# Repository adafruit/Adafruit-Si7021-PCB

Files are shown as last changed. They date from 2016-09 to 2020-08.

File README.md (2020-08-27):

## Adafruit Si7021 Temperature & Humidity Sensor Breakout PCB
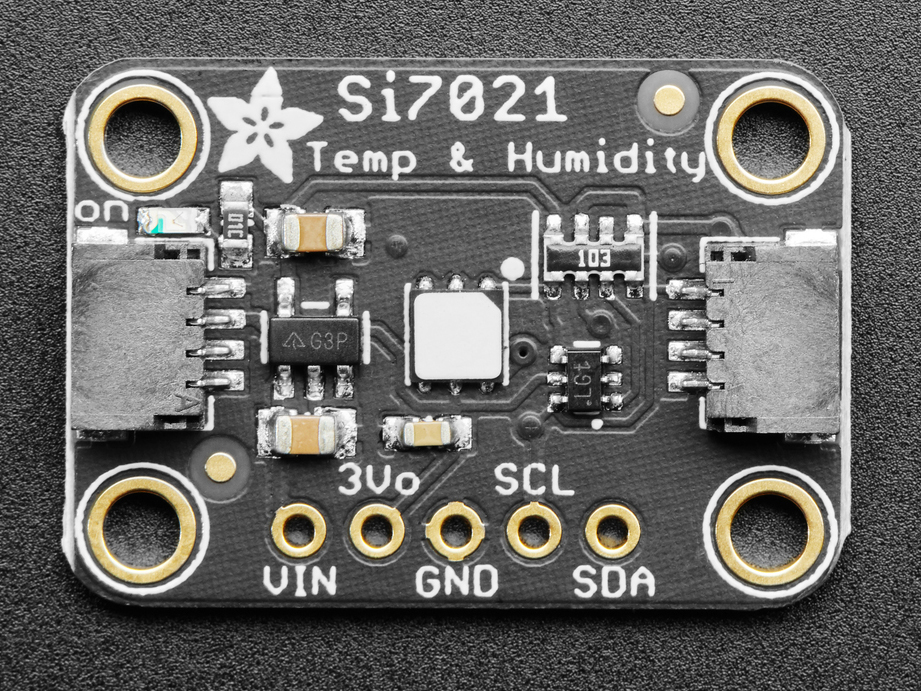
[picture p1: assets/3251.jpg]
<a href="http://www.adafruit.com/products/3251"><br/>
Click here to purchase one from the Adafruit shop</a>

It's summer and you're sweating and your hair's all frizzy and all you really want to know is why the weatherman said this morning that today's relative humidity would max out at a perfectly reasonable 42% when it feels more like 77%. Enter the Si7021 Temperature + Humidity Sensor - the best way to prove the weatherman wrong!

This lovely sensor for Silicon labs has ± 3% relative humidity measurements with a range of 0–80% RH, and ±0.4 °C temperature accuracy at a range of -10 to +85 °C. Great for all of your environmental sensing projects. It uses I2C for data transfer so it works with a wide range of microcontrollers.

To get you going fast, we spun up a custom made PCB in the STEMMA QT form factor, making them easy to interface with. The STEMMA QT connectors on either side are compatible with the SparkFun Qwiic I2C connectors. This allows you to make solderless connections between your development board and the LIS331s or to chain them with a wide range of other sensors and accessories using a compatible cable. We’ve of course broken out all the pins to standard headers and added a voltage regulator and level shifting so allow you to use it with either 3.3V or 5V systems such as the Raspberry Pi + Feather series or Arduino Uno respectively.

PCB files for the Adafruit Si7021 PCB. The format is EagleCAD schematic and board layout
- https://www.adafruit.com/products/3251

### License

Adafruit invests time and resources providing this open source design, please support Adafruit and open-source hardware by purchasing products from [Adafruit](https://www.adafruit.com)!

All text above must be included in any redistribution

Designed by Limor Fried/Ladyada for Adafruit Industries.
Creative Commons Attribution/Share-Alike, all text above must be included in any redistribution. 
See license.txt for additional information.

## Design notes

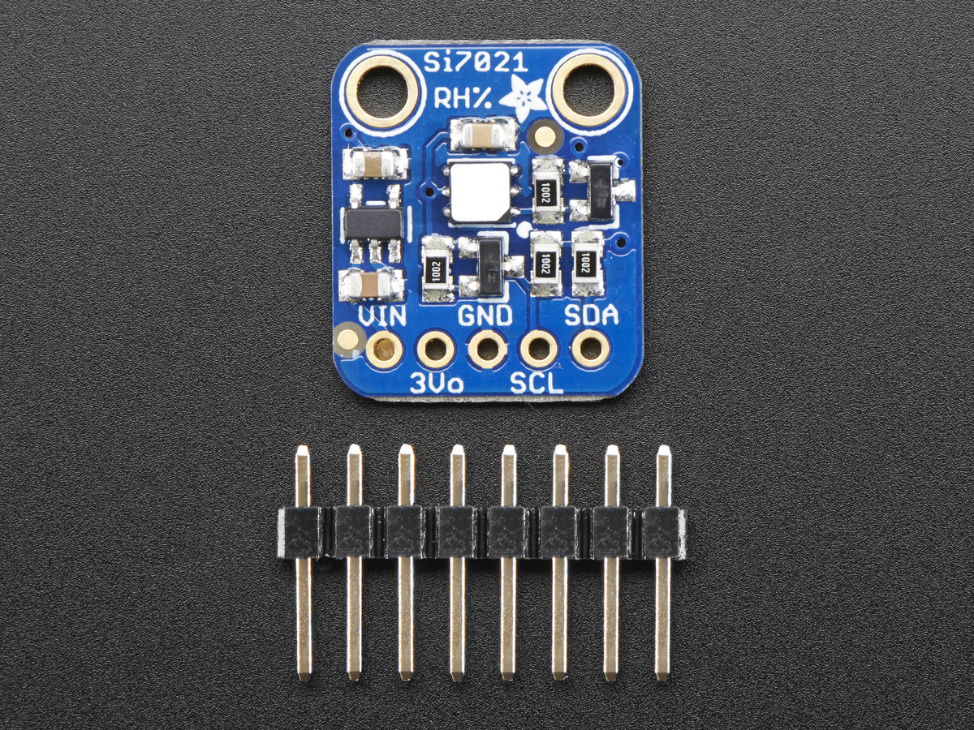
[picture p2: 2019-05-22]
assets/image.jpg

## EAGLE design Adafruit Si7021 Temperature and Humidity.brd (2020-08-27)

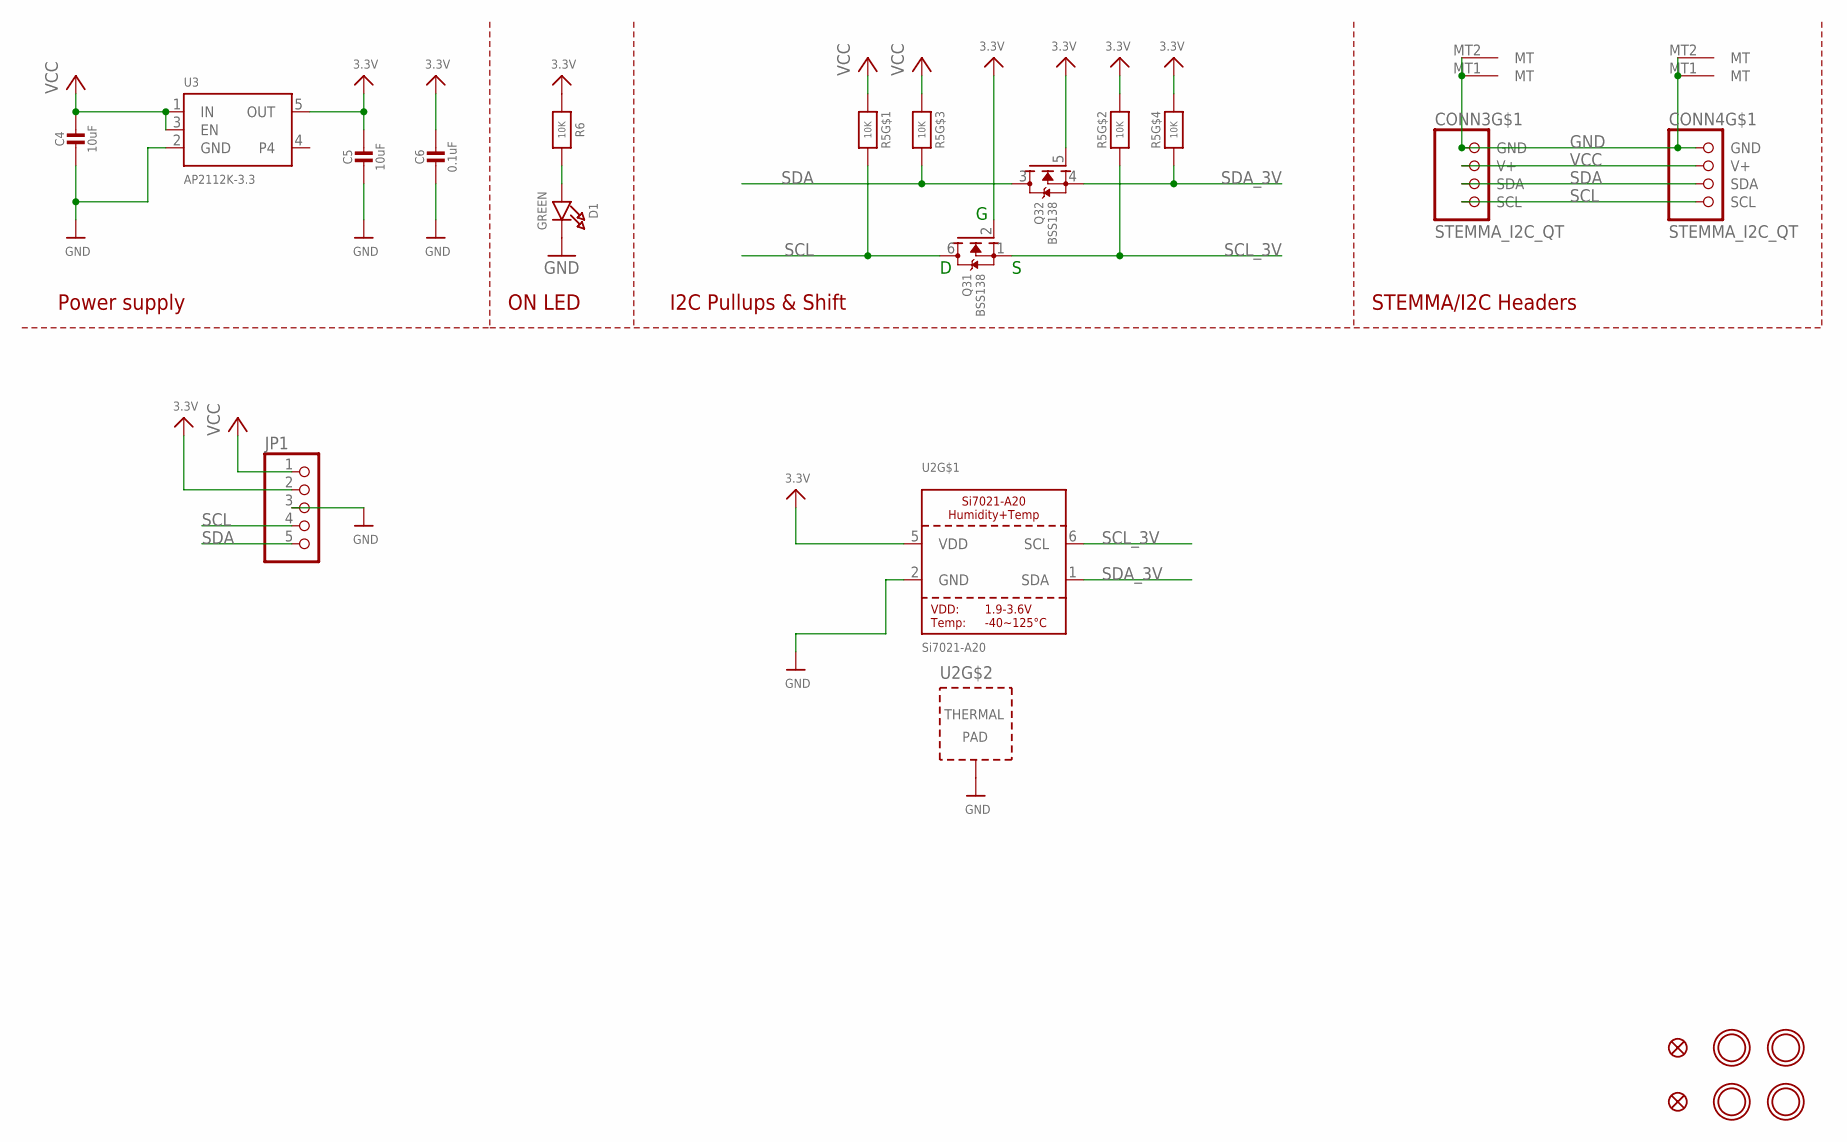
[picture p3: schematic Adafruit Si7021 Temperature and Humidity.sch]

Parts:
C4, C5: 10uF; 0805-NO
C6: 0.1uF; 0603-NO
CONN3, CONN4: STEMMA_I2C_QT; JST_SH4
D1: GREEN; CHIPLED_0603_NOOUTLINE
FID3, FID4: FIDUCIAL_1MM
JP1: HEADER-1X570MIL; 1X05_ROUND_70
Q3: BSS138; SOT363
R5: 10K; RESPACK_4X0603
R6: 10K; 0603-NO
U2: Si7021-A20; DFN6_3X3_SI
U3: AP2112K-3.3; SOT23-5
U$19, U$20, U$22, U$25: MOUNTINGHOLE2.5; MOUNTINGHOLE_2.5_PLATED

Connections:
3.3V: C5.1, C6.1, JP1.2, Q3.2 (G), Q3.5 (G), R5.2 (1), R5.4 (1), R6.1, U2.5 (VDD), U3.5 (OUT)
GND: C4.2, C5.2, C6.2, CONN3.1 (GND), CONN3.MT1 (MT), CONN3.MT2 (MT), CONN4.1 (GND), CONN4.MT1 (MT), CONN4.MT2 (MT), D1.C, JP1.3, U2.2 (GND), U2.PAD (TP), U3.2 (GND)
unnamed: D1.A, R6.2
SCL: CONN3.4 (SCL), CONN4.4 (SCL), JP1.4, Q3.6 (D), R5.8 (2)
SCL_3V: Q3.1 (S), R5.7 (2), U2.6 (SCL)
SDA: CONN3.3 (SDA), CONN4.3 (SDA), JP1.5, Q3.3 (D), R5.6 (2)
SDA_3V: Q3.4 (S), R5.5 (2), U2.1 (SDA)
VCC: C4.1, CONN3.2 (V+), CONN4.2 (V+), JP1.1, R5.1, R5.3 (1), U3.1 (IN), U3.3 (EN)

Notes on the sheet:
I2C Pullups & Shift
STEMMA/I2C Headers
ON LED
Power supply

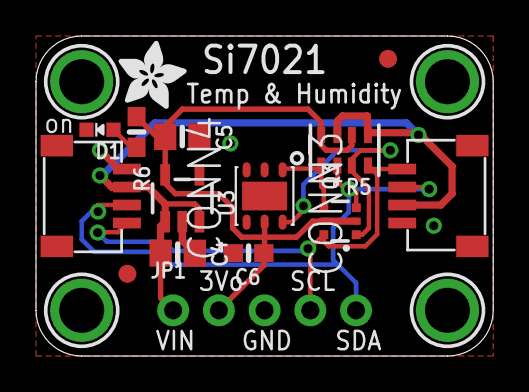
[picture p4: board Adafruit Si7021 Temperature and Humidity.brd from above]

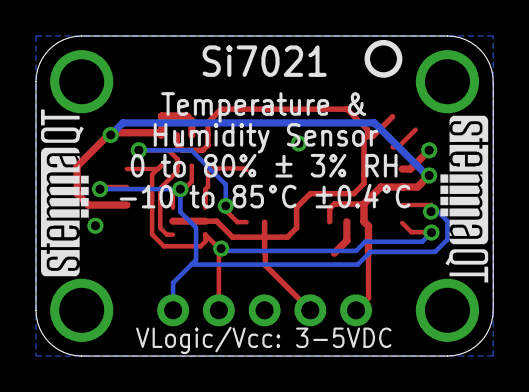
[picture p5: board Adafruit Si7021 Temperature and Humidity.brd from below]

Board: 2 copper layers, 25.4 x 17.8 mm, 22 parts (3 on the bottom side), 8 nets.

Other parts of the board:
U$28: ADAFRUIT_3.5MM
U$29: PCBFEAT-REV-040
U$30, U$31: STEMMAQT

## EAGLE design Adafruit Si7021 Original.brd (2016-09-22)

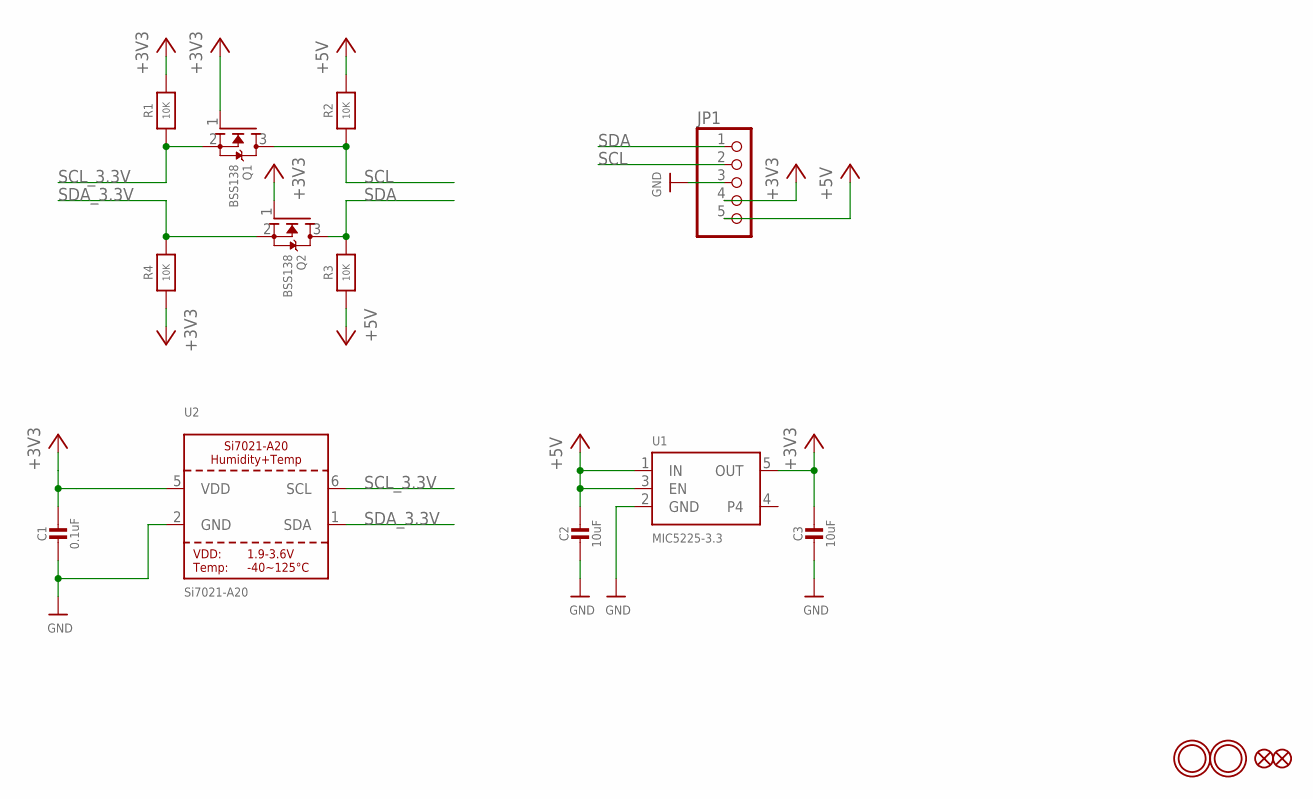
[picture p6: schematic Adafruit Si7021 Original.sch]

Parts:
C1: 0.1uF; 0805-NO
C2, C3: 10uF; 0805-NO
FID1, FID2: FIDUCIAL""; FIDUCIAL_1MM
JP1: HEADER-1X570MIL; 1X05_ROUND_70
Q1, Q2: BSS138; SOT23-WIDE
R1, R2, R3, R4: 10K; 0805-NO
U1: MIC5225-3.3; SOT23-5
U2: Si7021-A20; DFN6_3X3_SI
U$6, U$7: MOUNTINGHOLE2.5; MOUNTINGHOLE_2.5_PLATED

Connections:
+3V3: C1.1, C3.1, JP1.4, Q1.1 (G), Q2.1 (G), R1.2, R4.1, U1.5 (OUT), U2.5 (VDD)
GND: C1.2, C2.2, C3.2, JP1.3, U1.2 (GND), U2.2 (GND)
SCL: JP1.2, Q1.3 (D), R2.1
SCL_3.3V: Q1.2 (S), R1.1, U2.6 (SCL)
SDA: JP1.1, Q2.3 (D), R3.2
SDA_3.3V: Q2.2 (S), R4.2, U2.1 (SDA)
VIN: C2.1, JP1.5, R2.2, R3.1, U1.1 (IN), U1.3 (EN)

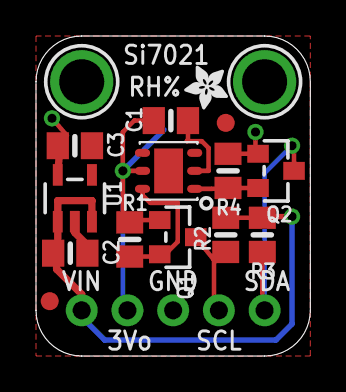
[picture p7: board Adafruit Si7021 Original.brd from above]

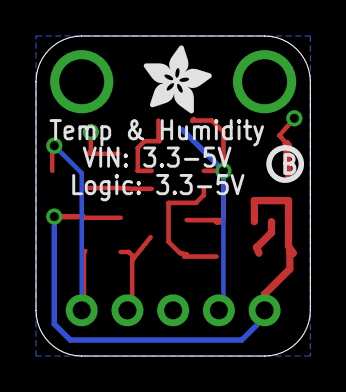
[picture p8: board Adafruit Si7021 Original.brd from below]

Board: 2 copper layers, 15.2 x 17.8 mm, 19 parts (2 on the bottom side), 7 nets.

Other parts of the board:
U$1: ADAFRUIT_2.5MM
U$9: PCBFEAT-REV-040
U$10: ADAFRUIT_3.5MM

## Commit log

2020-08-27 Rename file.
    [Adafruit Si7021 Original.brd]
2020-08-27 Add new board files.
    [Adafruit Si7021 Temperature and Humidity.brd, Adafruit Si7021 Temperature and Humidity.sch]

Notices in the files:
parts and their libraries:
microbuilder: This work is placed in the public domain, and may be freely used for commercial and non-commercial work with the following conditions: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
